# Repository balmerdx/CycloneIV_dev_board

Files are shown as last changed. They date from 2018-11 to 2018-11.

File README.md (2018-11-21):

# Отладочная плата на Cyclone IV

Это простая отладочная плата для FPGA Cyclone IV EP4CE10.
Кроме собственно FPGA на ней расположенны:
* 4 светодиода
* CP2102 для общения с компьютером по UART
* SPI Flash для записи прошивки
* JTAG
* 28 ножек FPGA для подключения пользовательских устройств

[Схема в pdf формате](https://github.com/balmerdx/CycloneIV_dev_board/blob/master/documentation/cp4ce10_0.pdf)

### Плата в KICAD

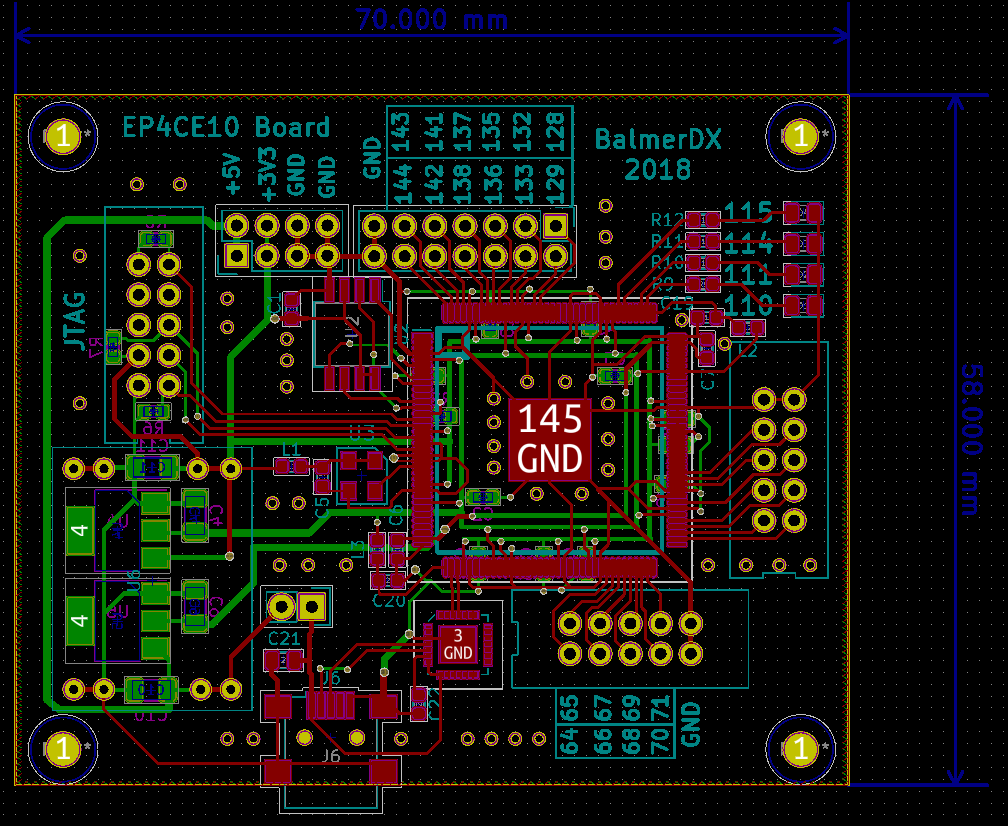
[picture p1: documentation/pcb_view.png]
KICAD shot


### Внешний вид

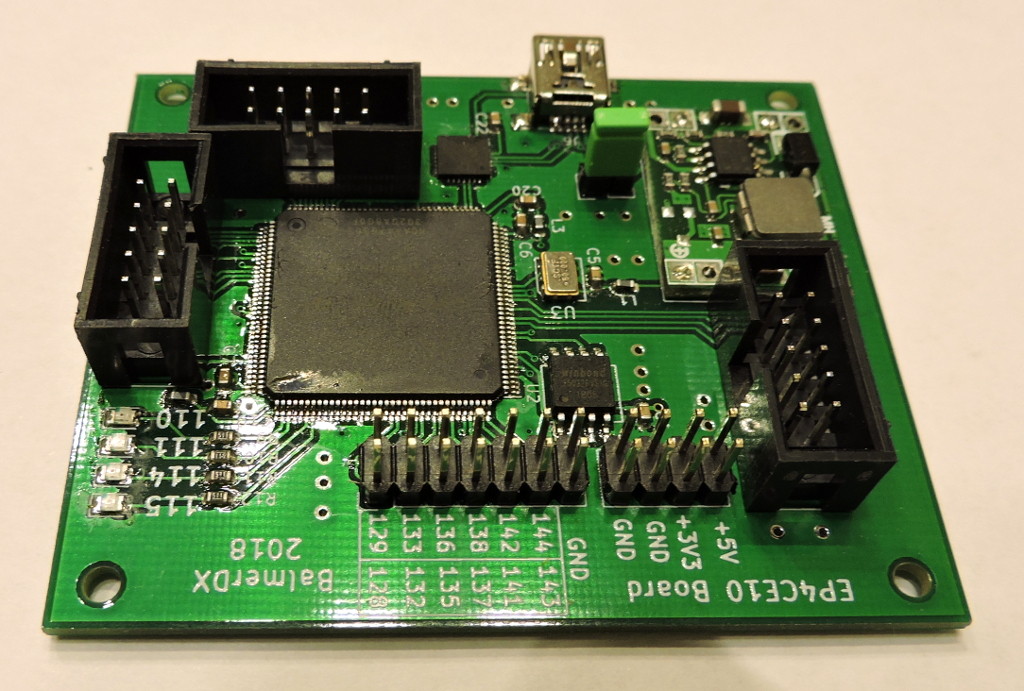
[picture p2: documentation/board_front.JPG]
Front

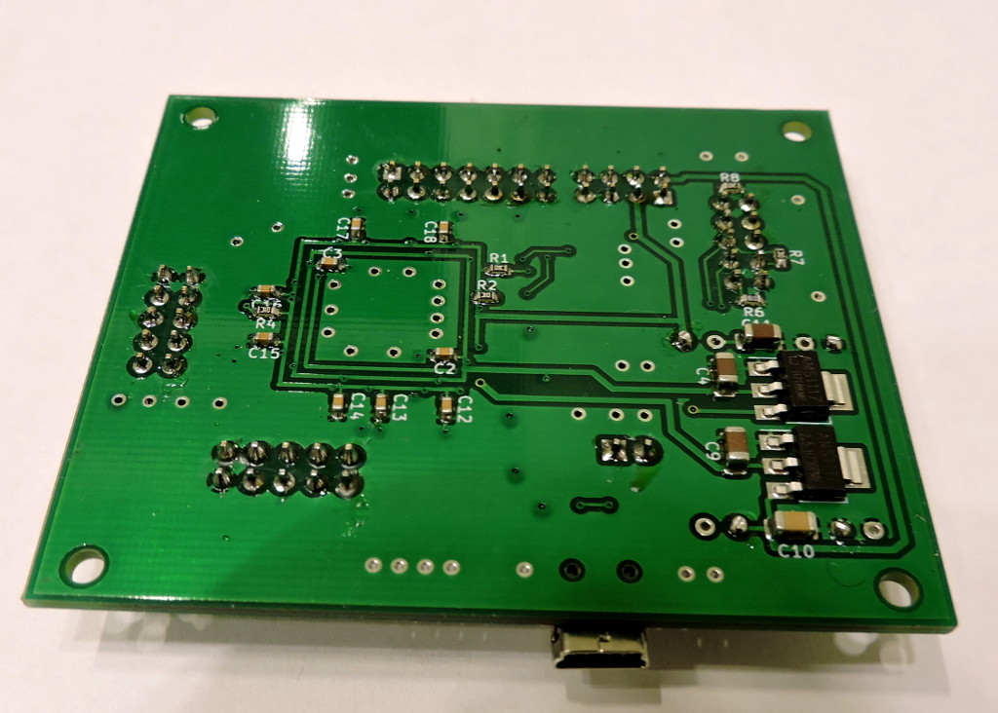
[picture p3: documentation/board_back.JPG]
Back


### Папки

В папке **ep4ce10_0** располагается собственно проект на KiCAD.
В папке examples пара примеров, работающих на ней.

**examples/test_my_board_led** - сравнительно простой пример, который умеет мигать светодиодами и принимать байт с командами по UART (на скорости 115200 bps). Пример общения с компьютером в файле examples/test_my_board_led/test_usart.py . Формат команды простой, посылаем 1 байт на устройство. Младшие 4 бита - состояние светодиодов (включенно/выключенно). Старший бит - переводит устройство в "самостоятельное плавание", когда оно начинает мигать светодиодиками самостоятельно.

**examples/test_my_board_advanced** - более сложный пример. Не только принимает команды по UART, но и отсылает в ответ строку, которую берет из заранее инициализированной памяти.

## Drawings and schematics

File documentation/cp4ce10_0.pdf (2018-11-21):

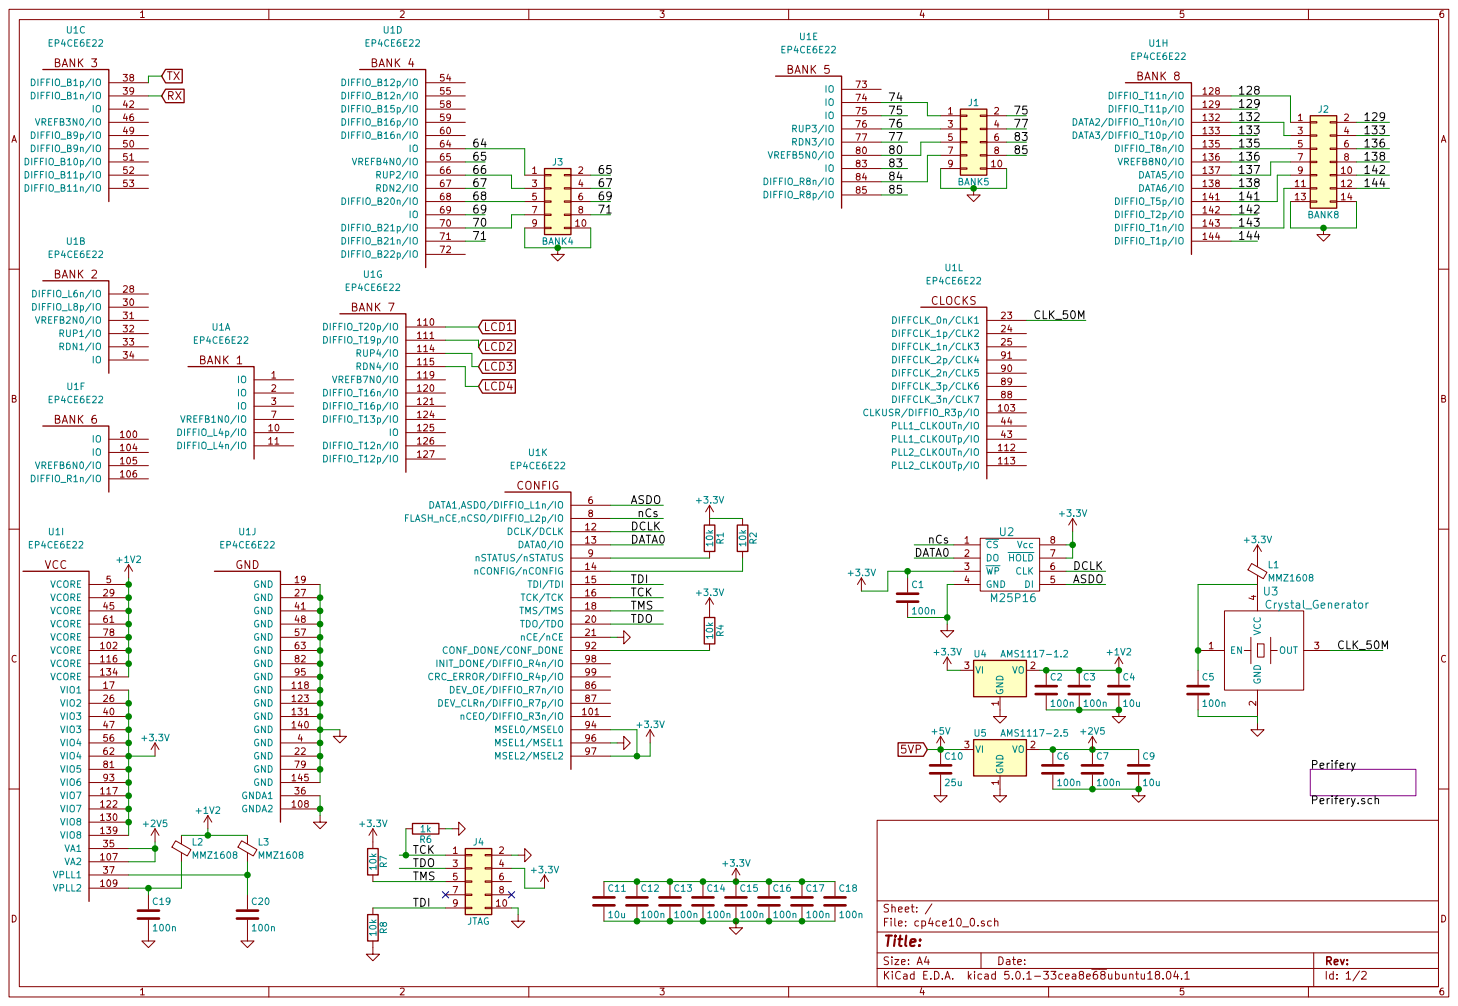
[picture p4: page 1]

1 VO 2 VI 3 U4 AMS1117-1.2 CS 1 DO 2 WP 3 GND 4 DI 5 CLK 6 HOLD 7 Vcc 8 U2 M25P16

TDO 3 | 4
TMS 5 | 6

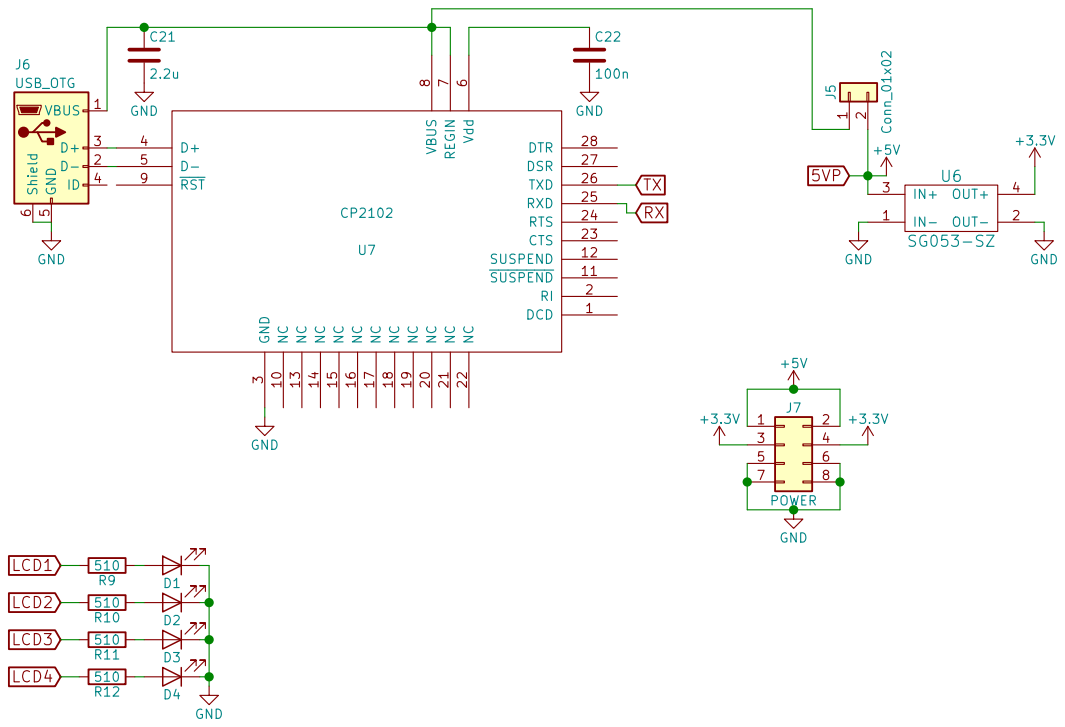
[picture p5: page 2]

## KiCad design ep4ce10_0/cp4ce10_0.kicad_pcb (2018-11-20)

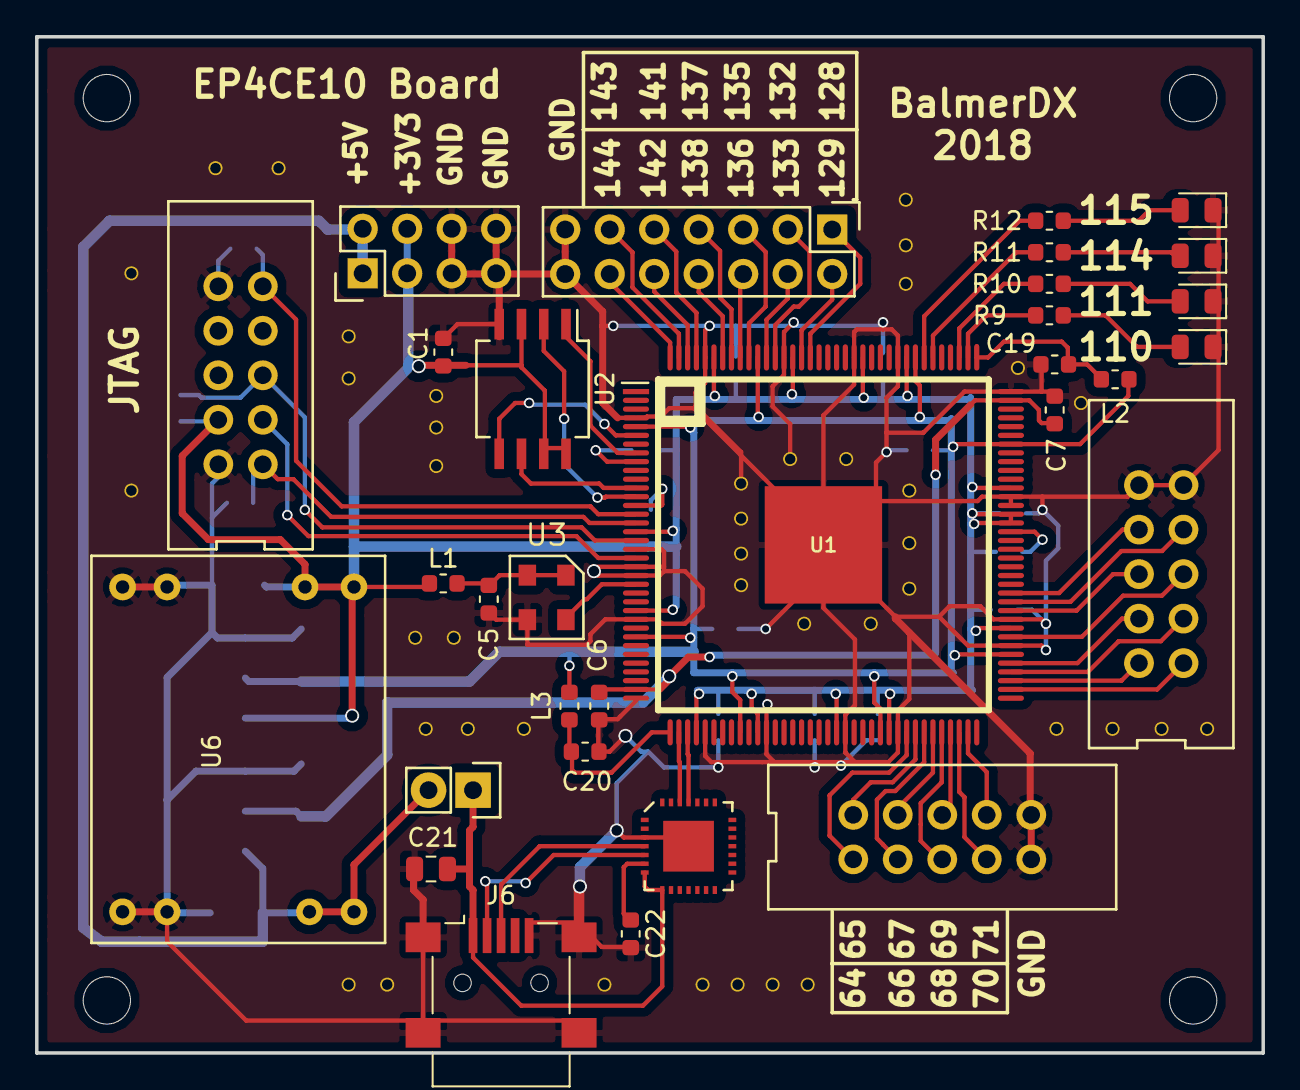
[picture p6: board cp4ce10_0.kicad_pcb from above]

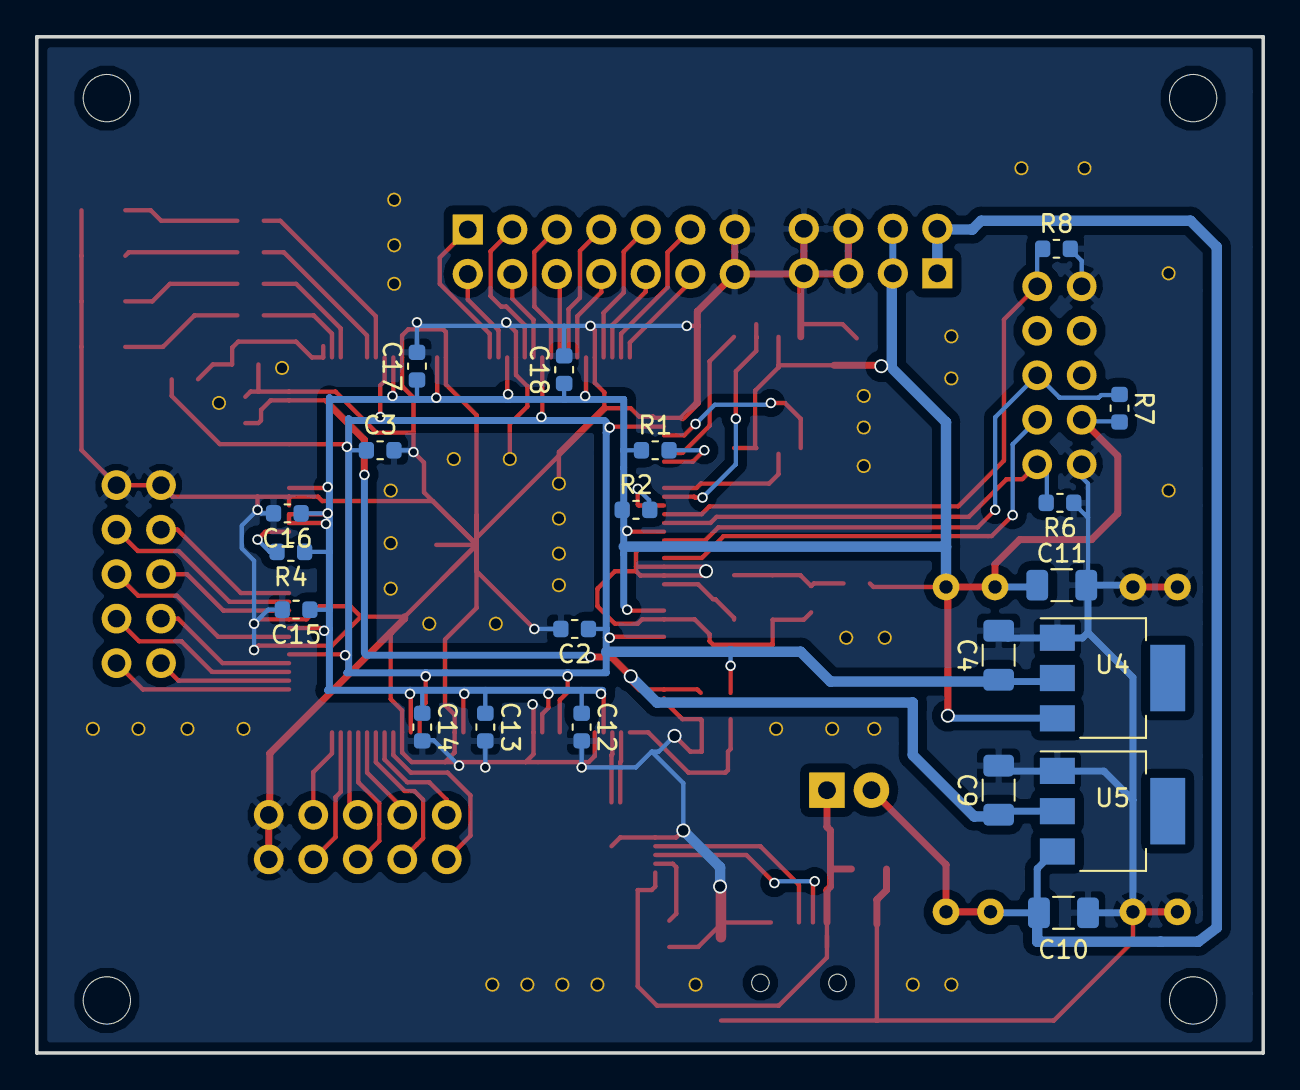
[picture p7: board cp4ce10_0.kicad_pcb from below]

Board: 2 copper layers, 70.0 x 58.0 mm, 52 parts (21 on the bottom side), 62 nets.

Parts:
C1, C2, C3, C5, C6, C7, C12, C13, C14, C15, C16, C17, C18, C19, C20, C22: 100n; C_0603_1608Metric
C4, C9, C11: 10u; C_1206_3216Metric
C10: 25u; C_1206_3216Metric
C21: 2.2u; C_0805_2012Metric
D1, D2, D3, D4: LED; LED_0805_2012Metric
J1: BANK5; IDC_10M
J2: BANK8; Pin_Header_Straight_2x07
J3: BANK4; IDC_10M
J4: JTAG; IDC_10M
J5: Conn_01x02; Pin_Header_Straight_1x02
J6: USB_OTG; USB_Mini-B_Lumberg_2486_01_Horizontal
J7: POWER; Pin_Header_Straight_2x04
L1, L2, L3: MMZ1608; C_0603_1608Metric
R1, R2, R4, R7, R8: 10k; R_0603_1608Metric
R6: 1k; R_0603_1608Metric
R9, R10, R11, R12: 510; R_0603_1608Metric
U1: EP4CE6E22; ALTERA-QFP-145
U2: M25P16; SO-8_5.3x6.2mm_P1.27mm
U3: Crystal_Generator; Crystal_5.0x3.2mm
U4: AMS1117-1.2; SOT-223
U5: AMS1117-2.5; SOT-223
U6: SG053-SZ
U7: CP2102; MLP-28

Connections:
5VP: C10.1, J5.2, J7.1, J7.2, U5.3, U6.3
+1V2: C2.1, C3.1, C4.1, L2.1, L3.1, U1.5, U1.29, U1.45, U1.61, U1.78, U1.102, U1.116, U1.134, U4.2
+2V5: C6.1, C7.1, C9.1, U1.35, U1.107, U5.2
+3V3: C1.1, C11.1, C12.1, C13.1, C14.1, C15.1, C16.1, C17.1, C18.1, J4.4, J7.3, J7.4, L1.1, R1.1, R2.1, R4.1, R7.1, U1.17, U1.26, U1.40, U1.47, U1.56, U1.62, U1.81, U1.93, U1.94, U1.97, U1.117, U1.122, U1.130, U1.139, U2.3, U2.7, U2.8, U4.3, U6.4
/64: J3.1, U1.64
/65: J3.2, U1.65
/66: J3.3, U1.66
/67: J3.4, U1.67
/68: J3.5, U1.68
/69: J3.6, U1.69
/70: J3.7, U1.70
/71: J3.8, U1.71
/74: J1.1, U1.74
/75: J1.2, U1.75
/76: J1.3, U1.76
/77: J1.4, U1.77
/80: J1.5, U1.80
/83: J1.6, U1.83
/84: J1.7, U1.84
/85: J1.8, U1.85
/128: J2.1, U1.128
/129: J2.2, U1.129
/132: J2.3, U1.132
/133: J2.4, U1.133
/135: J2.5, U1.135
/136: J2.6, U1.136
/137: J2.7, U1.137
/138: J2.8, U1.138
/141: J2.9, U1.141
/142: J2.10, U1.142
/143: J2.11, U1.143
/144: J2.12, U1.144
/ASDO: U1.6, U2.5
/CLK_50M: U1.23, U3.3
/DATA0: U1.13, U2.2
/DCLK: U1.12, U2.6
/TCK: J4.1, R6.2, U1.16
/TDI: J4.9, R8.1, U1.15
/TDO: J4.3, U1.20
/TMS: J4.5, R7.2, U1.18
/nCs: U1.8, U2.1
GND: C1.2, C2.2, C3.2, C4.2, C5.2, C6.2, C7.2, C9.2, C10.2, C11.2, C12.2, C13.2, C14.2, C15.2, C16.2, C17.2, C18.2, C19.2, C20.2, C21.2, C22.2, D1.1, D2.1, D3.1, D4.1, J1.9, J1.10, J2.13, J2.14, J3.9, J3.10, J4.2, J4.10, J6.5, J6.6, J7.5, J7.6, J7.7, J7.8, R6.1, R8.2, U1.4, U1.19, U1.21, U1.22, U1.27, U1.36, U1.41, U1.48, U1.57, U1.63, U1.79, U1.82, U1.95, U1.96, U1.108, U1.118, U1.123, U1.131, U1.140, U1.145, U2.4, U3.2, U4.1, U5.1, U6.1, U6.2, U7.3
LCD1: R9.2, U1.110
LCD2: R10.2, U1.111
LCD3: R11.2, U1.114
LCD4: R12.2, U1.115
unnamed: C5.1, L1.2, U3.1, U3.4
unnamed: C19.1, L2.2, U1.109
unnamed: C20.1, L3.2, U1.37
unnamed: C21.1, J5.1, J6.1, U7.7, U7.8
unnamed: C22.1, U7.6
unnamed: D1.2, R9.1
unnamed: D2.2, R10.1
unnamed: D3.2, R11.1
unnamed: D4.2, R12.1
unnamed: J6.2, U7.5
unnamed: J6.3, U7.4
unnamed: R1.2, U1.9
unnamed: R2.2, U1.14
unnamed: R4.2, U1.92
RX: U1.39, U7.25
TX: U1.38, U7.26

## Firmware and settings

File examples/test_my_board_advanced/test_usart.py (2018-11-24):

#!/usr/bin/env python3

import time
import serial
import sys
import struct

ser = None

def connect():
	global ser
	ser = serial.Serial(
		port='/dev/ttyUSB0',
		baudrate=115200,
		parity=serial.PARITY_NONE,
		stopbits=serial.STOPBITS_ONE,
		bytesize=serial.EIGHTBITS,
		timeout = 0.2
	)

	return ser.isOpen()

def close():
	ser.close()


if __name__ == "__main__":
	if not connect():
		print("Cannot connect to serial port")
		exit(1)

	if 1:
		ser.write([0b1110])
		#ser.write([0b0001])
		#ser.write([0x10])
		is_empty = False
		while True:
			line = ser.readline()
			if len(line)==0:
				is_empty = True
				print(".", end='')
				sys.stdout.flush()
				continue

			if is_empty:
				print("")
			is_empty = False
			#value = line.decode('latin1')[:-1]
			value = line
			print("value=", value)
		exit(1)


	for x in range(5):
		ser.write([0b1111])
		time.sleep(0.5)
		ser.write([0b0000])
		time.sleep(0.5)

	for x in range(5):
		ser.write([0b1001])
		time.sleep(0.5)
		ser.write([0b0110])
		time.sleep(0.5)

	ser.write([0x10]) #use time counter to blink leds
	#ser.write([0x10]) #all led off
	pass

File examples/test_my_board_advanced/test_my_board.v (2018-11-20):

module test_my_board (input clk_50M,
	input uart_rx_pin,
	output reg uart_tx_pin,
	output reg led110,
	output reg led111,
	output reg led114,
	output reg led115);

localparam UART_CLKS_PER_BIT = 434;//115200 bps
reg [25:0] count;
logic [3:0] leds;

reg use_leds_from_uart;
initial use_leds_from_uart = 0;

logic uart_rx_received;
wire [7:0] uart_rx_byte;

reg uart_tx_send_byte = 0;
reg uart_tx_active;
reg [7:0] uart_tx_byte;


//Первоначально посылаем message_id==0 'Device online\n'
//Это конечно не совсем честно, по хорошему надо паузу выдержать.
reg signal_send_message = 1;
reg [2:0] message_id = 0;


always @ (*)
begin
	led110 = leds[0];
	led111 = leds[1];
	led114 = leds[2];
	led115 = leds[3];
end

always @ ( posedge clk_50M)
begin
	count <= count+1'd1;
	if(uart_rx_received)
	begin
		//set bit 7 to use counter to leds
		casez (uart_rx_byte)
			8'b0000zzzz:
			begin
				leds <= uart_rx_byte[3:0];
				use_leds_from_uart <= 1;
				
				message_id <= 3'h2;//'Led data received\n'
				signal_send_message <= 1;
			end
			8'b00010000:
			begin
				use_leds_from_uart <= 0;
				
				message_id <= 3'h3;//'Use counter to led\n'
				signal_send_message <= 1;
			end
		endcase
	end
	
	if(signal_send_message)
	begin
		signal_send_message <= 0;
	end
	
	if(!use_leds_from_uart)
	begin
		case (count[25:23])
		0: begin leds <= 4'b1000; end
		1: begin leds <= 4'b0100; end
		2: begin leds <= 4'b0010; end
		3: begin leds <= 4'b0001; end
		4: begin leds <= 4'b0001; end
		5: begin leds <= 4'b0010; end
		6: begin leds <= 4'b0100; end
		7: begin leds <= 4'b1000; end
		endcase
	end
end

uart_rx 
  #(.CLKS_PER_BIT(UART_CLKS_PER_BIT))
	uart_rx0
  (
   .i_Clock(clk_50M),
   .i_Rx_Serial(uart_rx_pin),
   .o_Rx_DV(uart_rx_received),
   .o_Rx_Byte(uart_rx_byte)
   );
	
uart_tx 
  #(.CLKS_PER_BIT(UART_CLKS_PER_BIT))
   uart_tx0
  (
   .i_Clock(clk_50M),
   .i_Tx_DV(uart_tx_send_byte),
   .i_Tx_Byte(uart_tx_byte), 
   .o_Tx_Active(uart_tx_active),
   .o_Tx_Serial(uart_tx_pin),
	.o_Tx_Done()
   );
	
uart_send_message uart_send_message0(
	.clock(clk_50M),
	.signal_send_message(signal_send_message),
	.message_id(message_id),
	.uart_tx_active(uart_tx_active),
	.uart_tx_send_byte(uart_tx_send_byte),
	.uart_tx_byte(uart_tx_byte));

endmodule

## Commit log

2018-11-20 KiCAD 5 board files
    [Perifery.sch, cp4ce10_0.kicad_pcb, cp4ce10_0.sch]
2018-11-20 Examples LED, UART, Memory Access
2018-11-21 schematic pdf
2018-11-24 - питон для com порта
